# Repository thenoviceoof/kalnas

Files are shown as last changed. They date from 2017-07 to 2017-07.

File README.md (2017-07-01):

KALNAS
--------------------------------------------------------------------------------

A NAS system designed to fit within the KALLAX bookshelves from IKEA.

[Design blog post](http://thenoviceoof.com/blog/projects/kalnas/)

WARNING: this design has never actually been made/put
together. However, all the designs were about to be sent out for
fabrication, so it *might* only require minor tweaks.

Example minor tweak: a remaining open question is how exactly to
connect the drive bays to the frame. The plan was to 3d print a nut
that fit within the T-slots and then screw the drive bays into
that. The nut has not been designed.

Files
--------------------------------------------------------------------------------
- 3d_mock.blend: a visualization of the final product.

- *.fcstd: FreeCAD design files, for more complicated designs.

  - front_panel_outline.fcstd: ports for 140mm intake fans.

  - back_panel_outline.fcstd: 140mm outflow fan, PSU mount.

  - mobo.fcstd: motherboard standoff mount points.

- p3__*.svg: Laser cutting files for Ponoko, using their 6.4mm
  melamine MDF boards.

- *.svg: intermediate design files.

- corsair_500R_drawings: a set of drawings/dimensions for the Corsair
  500R 3 drive bay, produced while I was designing the case around
  this bay. Everything is provided as is and without warranty, but
  it's worth re-iterating for this: I bought and measure the bay, but
  the part may change, or I may have screwed up the measurements.

80/20 Dimensions/parts
--------------------------------------------------------------------------------
The latest version uses 1 inch 80/20 struts as a frame. As planned,
everything has end taps, so you can screw directly into the ends of
the struts.

Strut dimensions:

- 4x 284.2mm. Vertical struts.

- 2x 339.2mm, access holes at 55.95, 109.45mm. Front-to-back strut,
  top.

- 2x 339.2mm, access holes at 55.95, 109.45, 226.5mm. Front-to-back
  strut, bottom. The extra holes are to accomodate a bar to support
  the PSU.

- 9x 160mm. Side-to-side struts, both for the external frame (4x) and
  internal supports for the PSU and drive bays (5x).

- 8x corner brackets
  ([McMaster-Carr](https://www.mcmaster.com/#47065t244/=17iepme),
  [80/20](https://8020.net/shop/4042.html)).

- 10x internal connectors ([80/20](https://8020.net/shop/3895.html)).

Where to get struts:

- [80/20](https://8020.net/shop/1010-s.html)

- [McMaster-Carr](https://www.mcmaster.com/#47065t101/=18b62b0)

Other parts
--------------------------------------------------------------------------------
- Planned drive bay used Corsair 500R 3 drive bays, one mounted right
  side up, the other mounted upside down from the top.

- Motherboard standoffs.

- The usual 6-32 and M3 screws for computer parts, 1/4in-20 screws for
  the frame corner connectors.

LICENSE
--------------------------------------------------------------------------------
CC-BY 4.0

https://creativecommons.org/licenses/by/4.0/

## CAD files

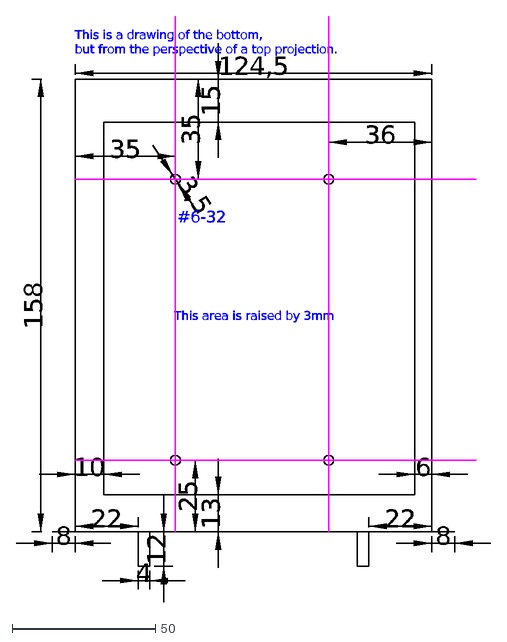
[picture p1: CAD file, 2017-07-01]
corsair_500R_drawings/corsair_500R_bottom.dxf
158
8
124,5
22
35
36
25
3,5
10
6
13
15
#6-32
12
4
This area is raised by 3mm
This is a drawing of the bottom, but from the perspective of a top projection.

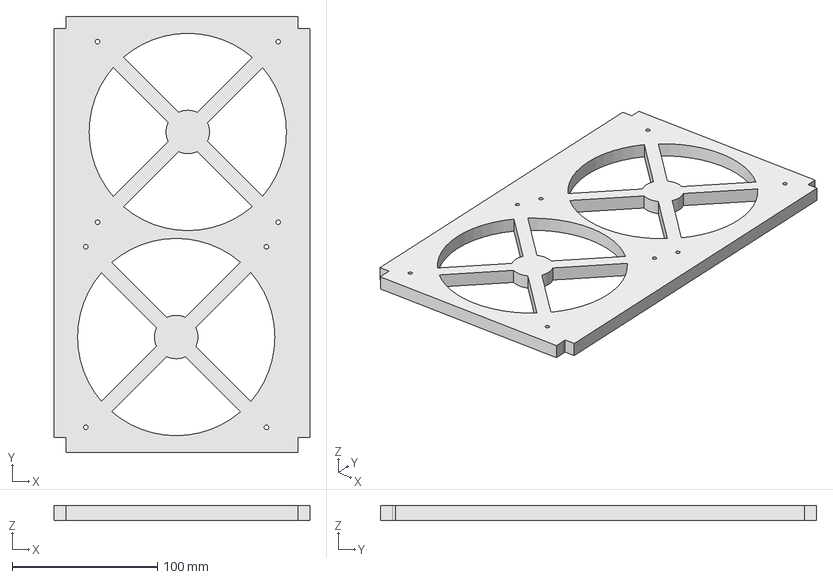
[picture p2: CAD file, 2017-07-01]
front_panel_outline.fcstd
176.4 x 300.6 x 10.0 mm

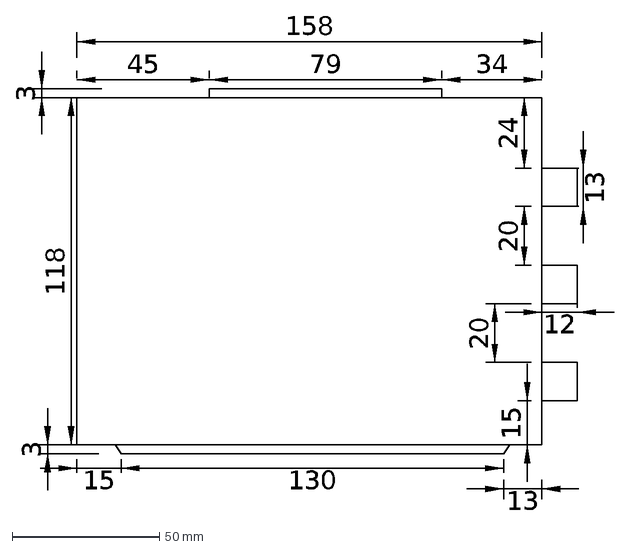
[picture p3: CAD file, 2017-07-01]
corsair_500R_drawings/corsair_500R_side.dxf
118
3
79
130
13
12
20
24
15
45
34
158

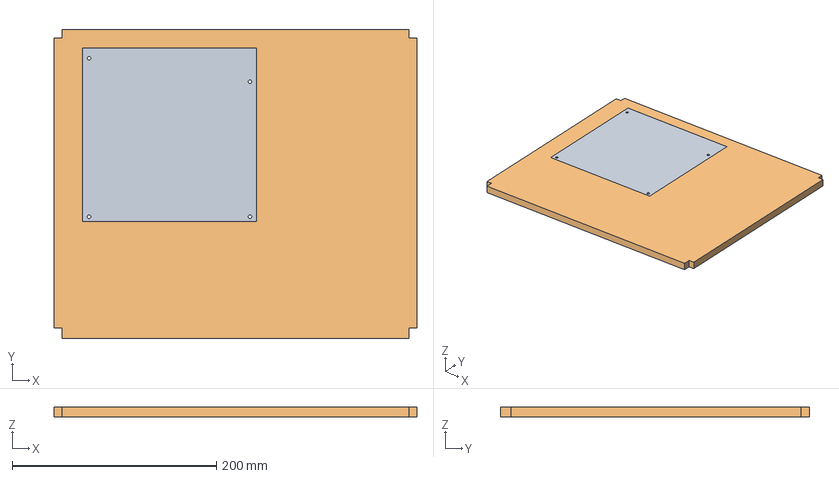
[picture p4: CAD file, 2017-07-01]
mobo.fcstd
355.2 x 302.2 x 10.0 mm

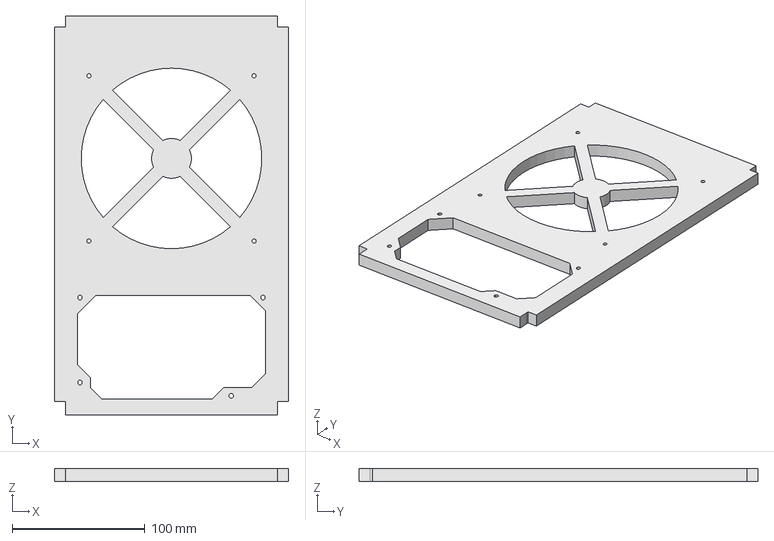
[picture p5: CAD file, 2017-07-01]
back_panel_outline.fcstd
176.4 x 300.6 x 10.0 mm

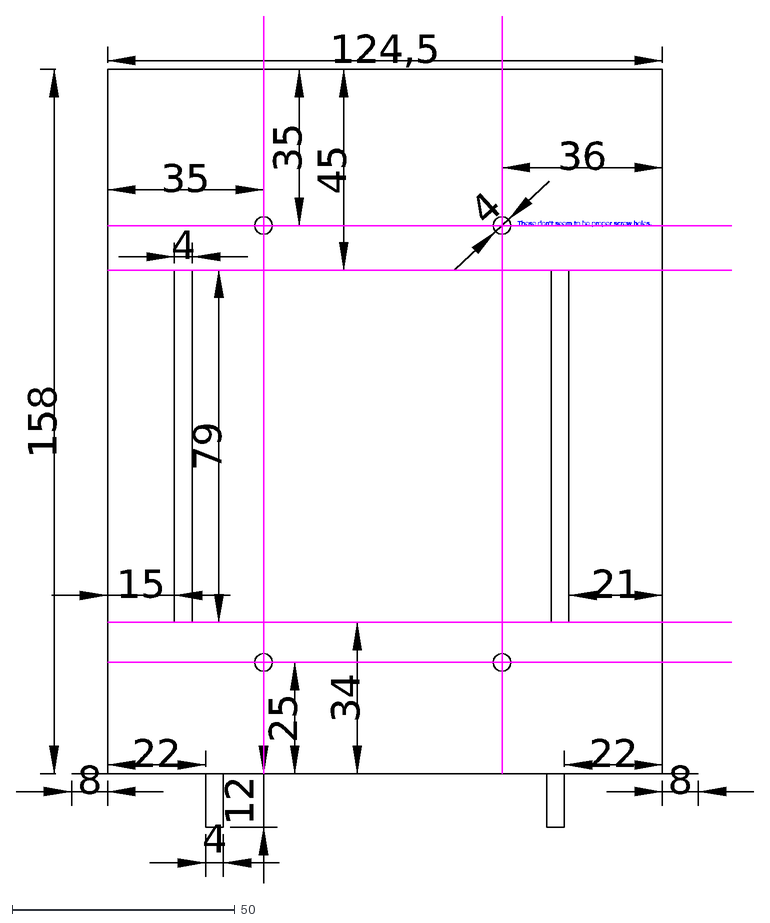
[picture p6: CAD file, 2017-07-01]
corsair_500R_drawings/corsair_500R_top.dxf
158
8
124,5
22
35
36
25
15
45
34
79
4
21
12
These don't seem to be proper screw holes.

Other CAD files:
3d_mock.blend

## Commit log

2017-03-26 Outline the cuts for the front panel; no actual cuts laid out yet.
    [front_panel_outline.fcstd]
2017-03-26 Layout cuts for a fan window
    [front_panel_outline.fcstd]
2017-03-28 Re-do the previous work in FreeCAD 0.16
    [front_panel_outline.fcstd]
2017-03-28 Design the fan cutouts
    [front_panel_outline.fcstd]
2017-04-15 Add blender file for 3d mock up
    [KALNAS_3d_mock.blend]
2017-07-01 Take 2 render model
    [KALNAS_3d_mock.blend]
2017-07-01 Add take 2 front/back/motherboard panel designs
    [back_panel_outline.fcstd, front_panel_outline.fcstd, mobo.fcstd]
2017-07-01 Rename the redundant KALNAS_ prefix away
    [3d_mock.blend]
2017-07-01 Add the dimensions/drawings for the Corsair 500R
    [corsair_500R_bottom.dxf, corsair_500R_side.dxf, corsair_500R_top.dxf]
